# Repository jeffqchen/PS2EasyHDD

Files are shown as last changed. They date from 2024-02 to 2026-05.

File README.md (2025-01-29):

# PS2 EasyHDD

Many PS2 players use HDL/OPL with a traditional hard drive or SSD. This requires the PS2 network adapter. In order to transfer games quickly and reliably, removing the drive and hooking it up to a computer is the definitive method.

However, the adapter has an annoying design - it contains the hard drive inside the PS2 and requires unscrewing the adapter from the PS2 in order to gain access to the drive. I have endured this annoyance for two decades, and decided it is time to end this. (Not to mention the color-mismatch when you use a special edition PS2...)


  

This is the EasyHDD shell for the PS2 network adapters. It simply reverses the way the hard drive is installed and allows you to easily pull it out.

You only need to disassemble the original network adapter, and transplant necessary parts to the new shell to finish the job. The unused parts will not be harmed and you can simply stow them away.

Since the hard drive bay inside the PS2 is constrained, currently only 2.5 inch SATA drives are in the plans to be supported.

There are currently 3 main variants of the network adapter:
- SCPH-10350. The thin model with only a LAN port.
- SCPH-10281. The thick model with both a modem and a LAN port.
- Gamestar. A piece of bootleg hardware that only offers hard drive connectivity and no networking is implemented.




The plan is to support all of the mentioned models.

Current progress:
- SCPH-10350: Finished
- SCPH-10281: Finished
- Game Star: Finished

Please visit the [Project Wiki](https://github.com/jeffqchen/PS2EasyHDD/wiki) page for detailed instructions.

-----

# Special Thanks

Twitter Folks for Photos:
- @radiatedguinea
- @MrBildo

-----

Shield: [][cc-by-sa]

This work is licensed under a
[Creative Commons Attribution-ShareAlike 4.0 International License][cc-by-sa].

[][cc-by-sa]

[cc-by-sa]: http://creativecommons.org/licenses/by-sa/4.0/
[cc-by-sa-image]: https://licensebuttons.net/l/by-sa/4.0/88x31.png
[cc-by-sa-shield]: https://img.shields.io/badge/License-CC%20BY--SA%204.0-lightgrey.svg

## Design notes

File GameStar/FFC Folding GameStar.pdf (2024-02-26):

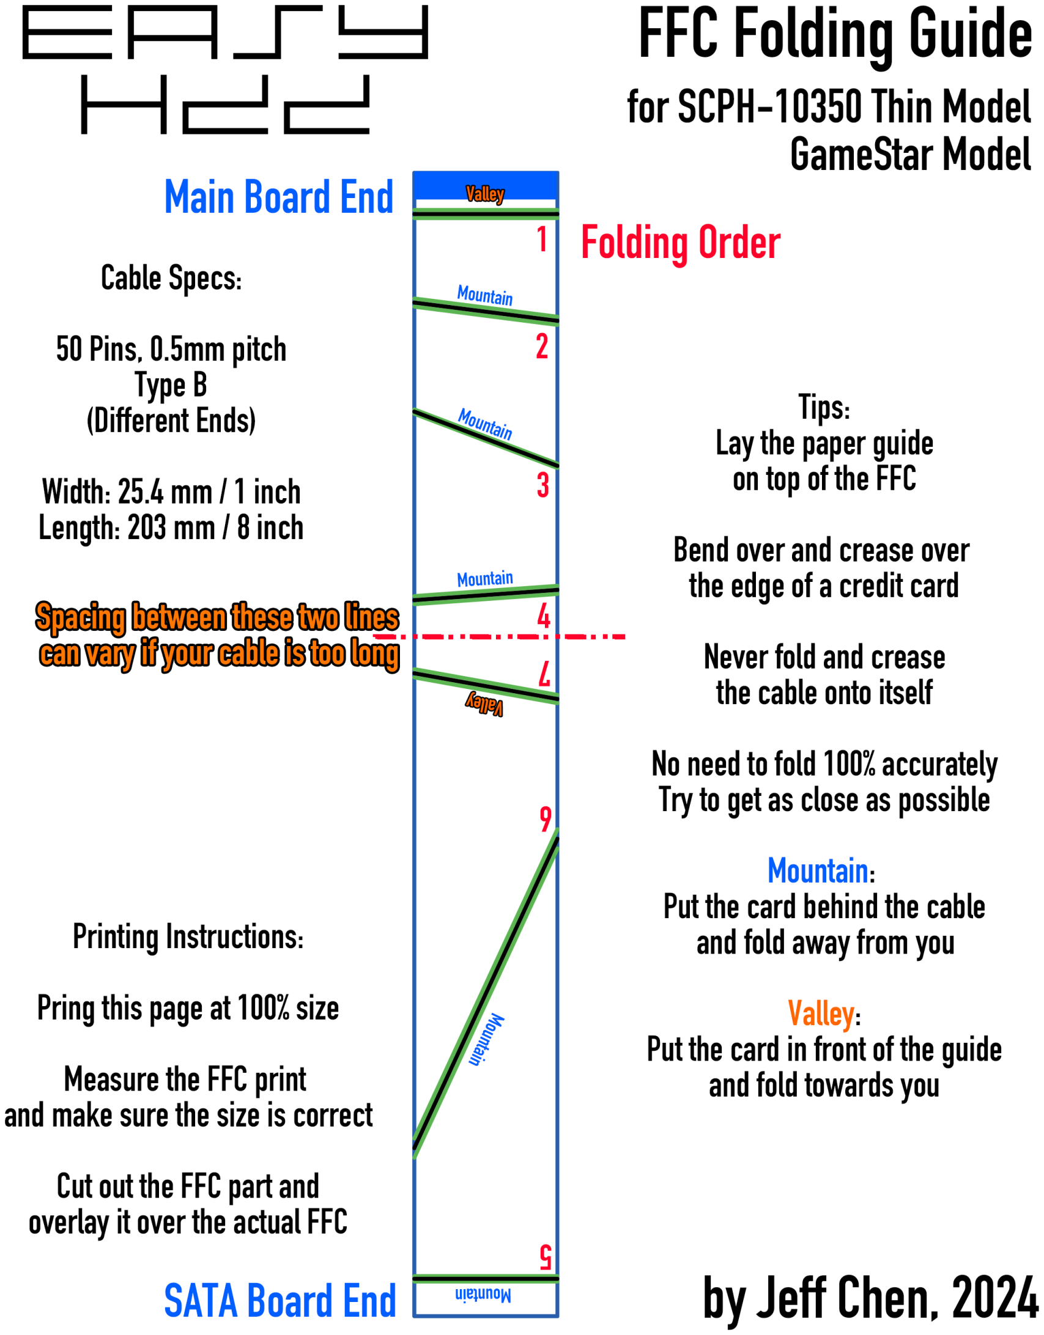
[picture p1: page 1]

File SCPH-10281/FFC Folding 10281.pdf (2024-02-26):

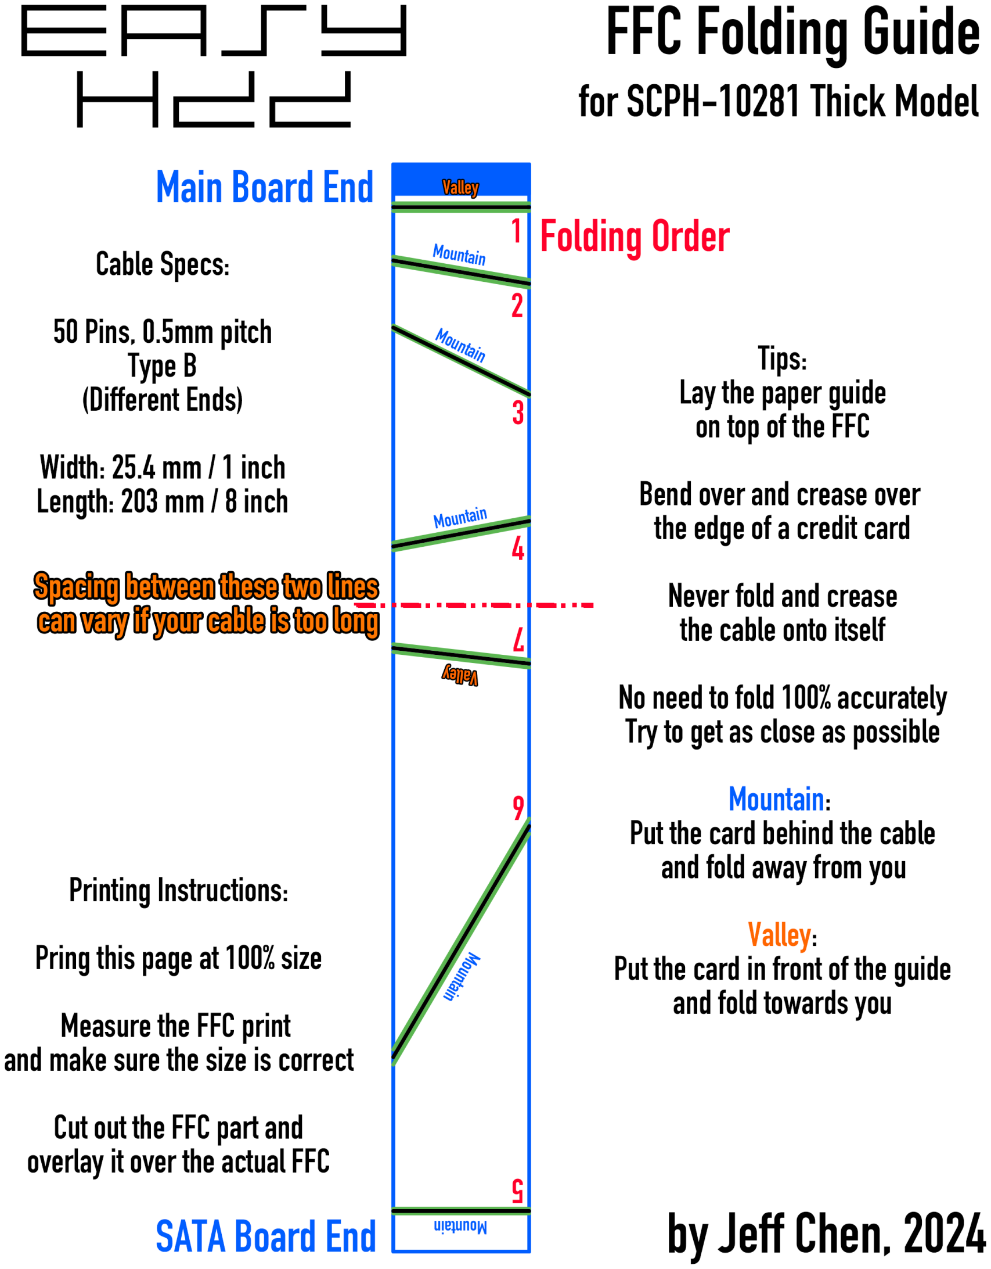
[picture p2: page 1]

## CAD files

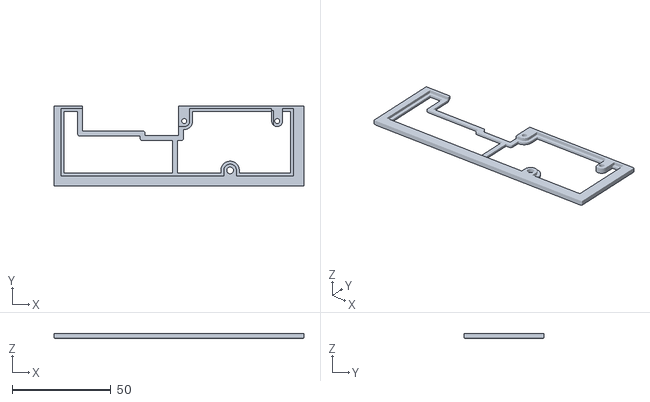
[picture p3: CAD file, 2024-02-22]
GameStar/3D Printing/Models Included In AIO/Main PCB Cover.stl
126.4 x 40.7 x 2.75

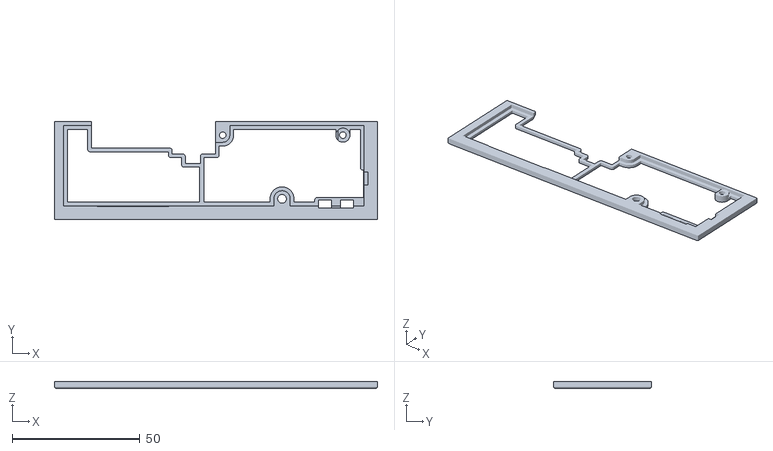
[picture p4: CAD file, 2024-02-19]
SCPH-10350/3D Printing/Models Included In AIO/Main PCB Cover.stl
126.4 x 38.2 x 2.75

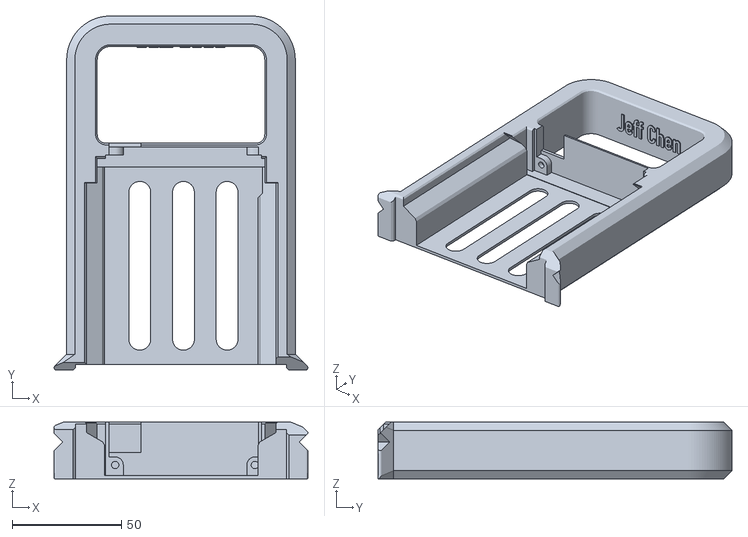
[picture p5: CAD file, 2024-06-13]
GameStar/3D Printing/Inner Tray Long.stl
116.3 x 162.2 x 26.0

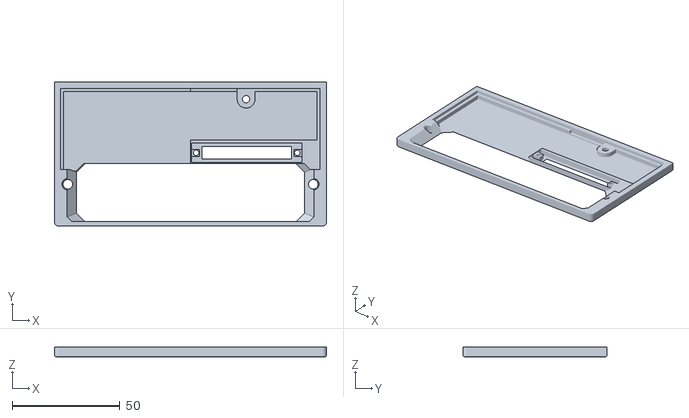
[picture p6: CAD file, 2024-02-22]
GameStar/3D Printing/Models Included In AIO/Inner Shell.stl
126.4 x 66.9 x 4.65

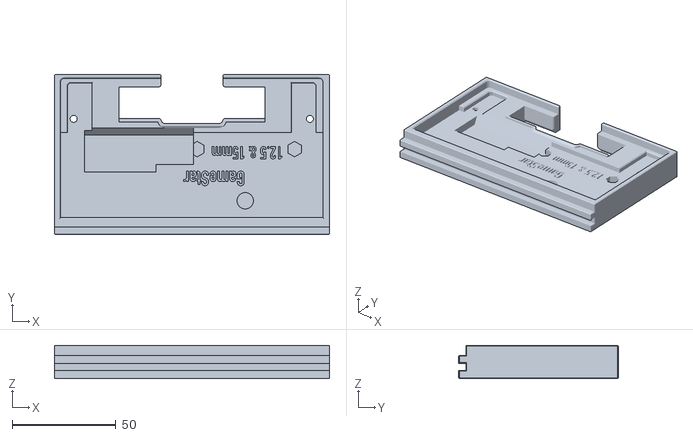
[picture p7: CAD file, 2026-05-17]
GameStar/3D Printing/Outer Shell & Tray Cover/Thick/Outer Shell 15mm.stl
132.8 x 77.0 x 16.1

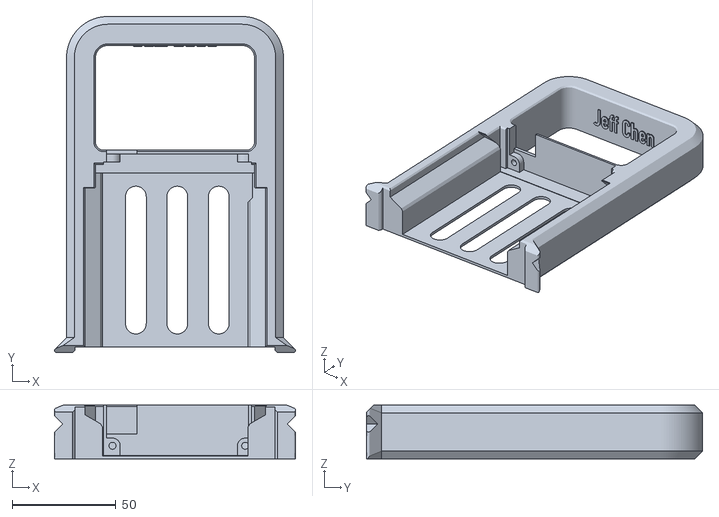
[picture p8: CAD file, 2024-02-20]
SCPH-10281/3D Printing/Inner Tray Long.stl
116.3 x 162.2 x 26.0

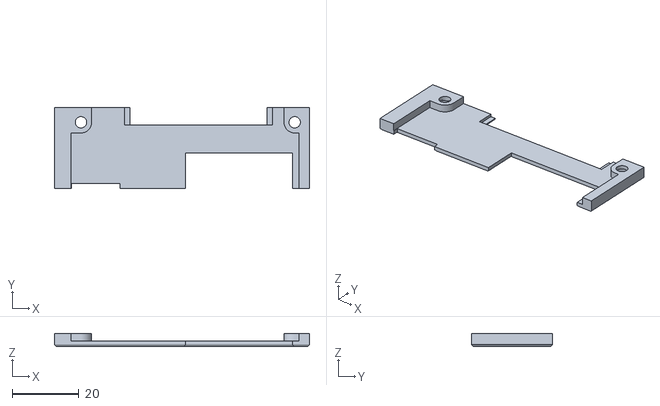
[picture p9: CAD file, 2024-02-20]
SCPH-10281/3D Printing/Models Included In AIO/Sata Board Cover.stl
76.3 x 24.4 x 3.82

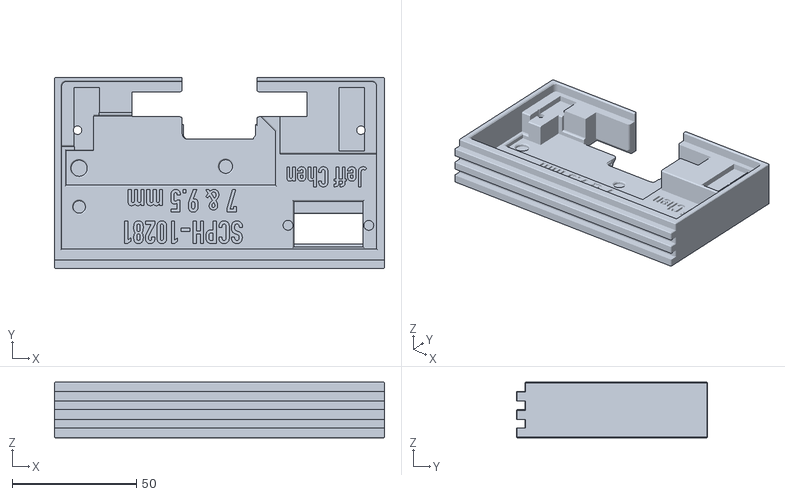
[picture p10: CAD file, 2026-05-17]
SCPH-10281/3D Printing/Outer Shell & Tray Cover/Outer Shell.stl
132.8 x 77.0 x 22.4

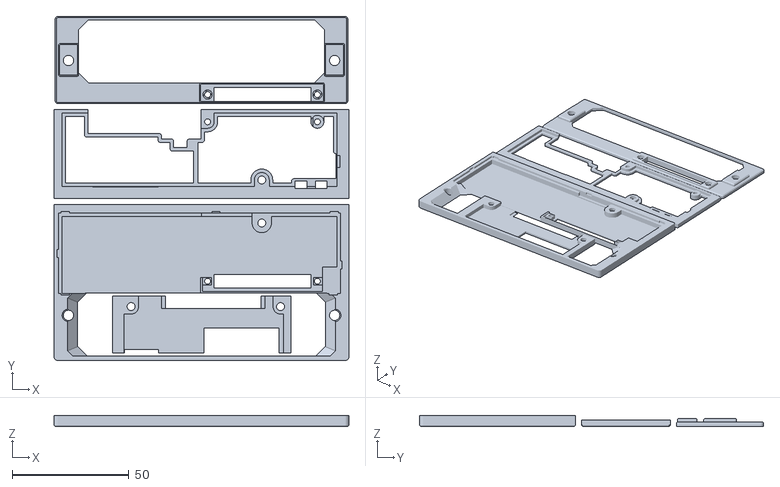
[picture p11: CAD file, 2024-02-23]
SCPH-10350/3D Printing/AIO for SCPH-10350.stl
126.4 x 147.4 x 4.65

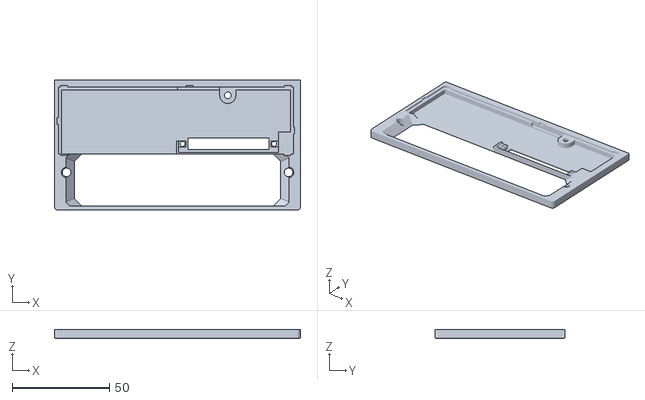
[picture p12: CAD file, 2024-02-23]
SCPH-10350/3D Printing/Models Included In AIO/Inner Shell.stl
126.4 x 66.9 x 4.65

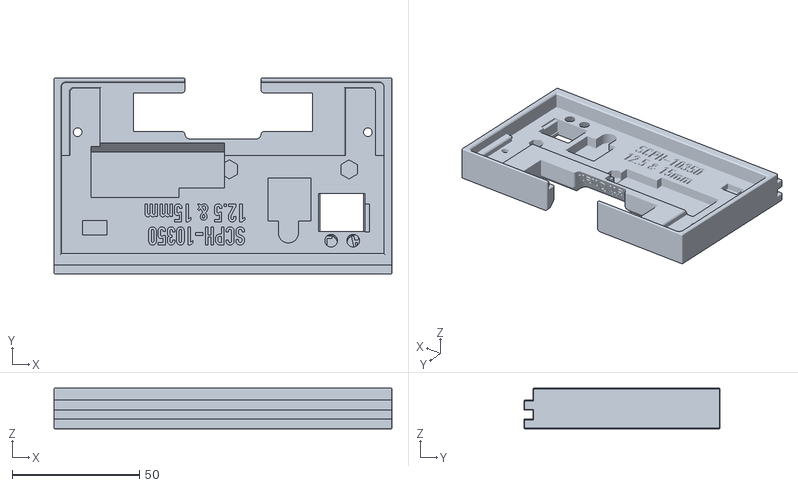
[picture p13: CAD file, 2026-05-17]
SCPH-10350/3D Printing/Outer Shell & Tray Cover/Thick/Outer Shell 15mm SPECIAL.stl
132.8 x 77.0 x 16.1

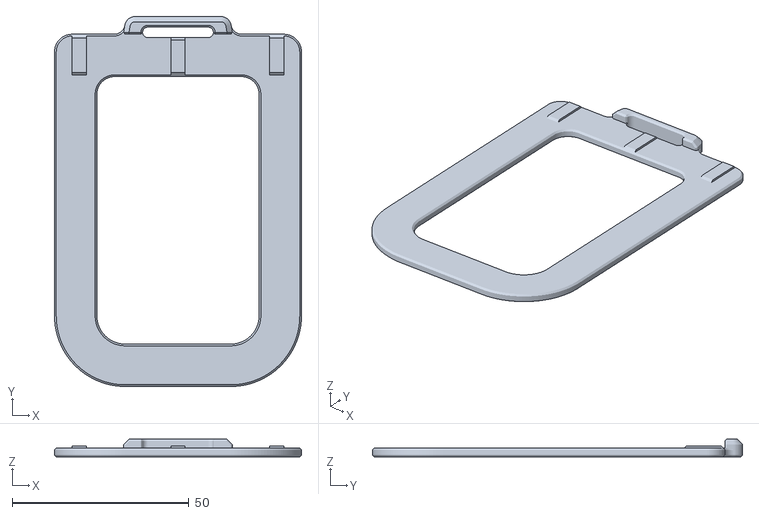
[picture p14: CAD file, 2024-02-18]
Tray Height Adapter.stl
69.9 x 104.6 x 5.00

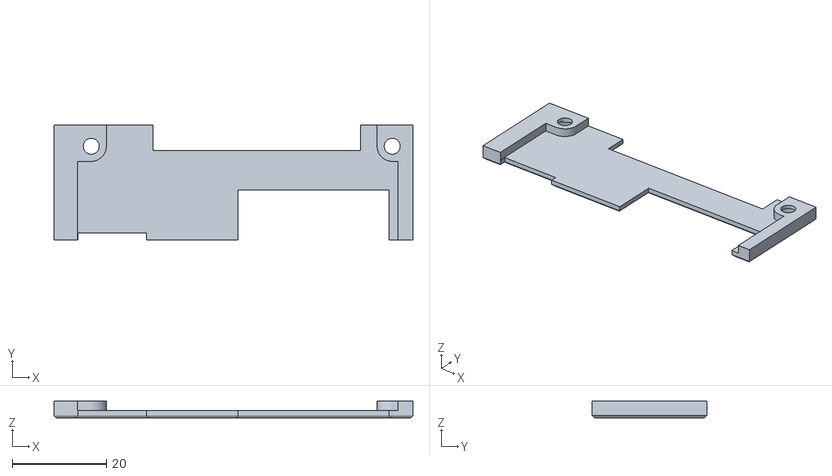
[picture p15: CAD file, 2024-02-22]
GameStar/3D Printing/Models Included In AIO/Sata Board Cover.stl
76.3 x 24.4 x 3.57

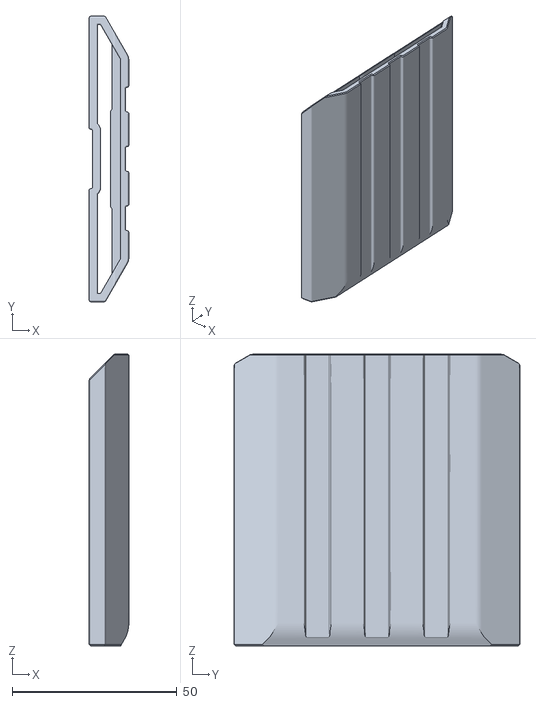
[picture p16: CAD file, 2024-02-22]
GameStar/3D Printing/Outer Shell & Tray Cover/Thick/Inner Tray Cover 12.5mm.stl
12.0 x 86.6 x 88.6

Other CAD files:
GameStar/3D Printing/Outer Shell & Tray Cover/Thin/Outer Shell 9.5mm.stl
SCPH-10350/3D Printing/Outer Shell & Tray Cover/Thin/Outer Shell 9.5mm.stl
GameStar/3D Printing/AIO for GameStar.stl
GameStar/3D Printing/Outer Shell & Tray Cover/Thin/Inner Tray Cover 9.5mm.stl
GameStar/3D Printing/Inner Tray Short.stl
GameStar/3D Printing/Models Included In AIO/Inner Spacer.stl
GameStar/3D Printing/Outer Shell & Tray Cover/Thick/Inner Tray Cover 15mm.stl
GameStar/3D Printing/Outer Shell & Tray Cover/Thin/Inner Tray Cover 7mm.stl
SCPH-10281/3D Printing/AIO for SCPH-10281.stl
SCPH-10281/3D Printing/Inner Tray Short.stl
SCPH-10281/3D Printing/Models Included In AIO/Inner Shell.stl
SCPH-10281/3D Printing/Models Included In AIO/Inner Spacer.stl
SCPH-10281/3D Printing/Models Included In AIO/Mid Frame.stl
SCPH-10281/3D Printing/Modem Board Cover.stl
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

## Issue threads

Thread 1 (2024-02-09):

Support for V1.0 purple SATA interface board

burgsth, 2024-02-09:
I have a V1.0 purple SATA interface board with a slightly different component layout.
It won't fit into the printed part.

If needed I can add more dimension informations.
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

jeffqchen, 2024-02-10:
I don't have the v1.0 board on hand, but I have found pictures online. This will not be accurate and could lead to issues. And it will take a bit of time to add to the models.

If you can't wait, consider getting a v2.0 for now.

jeffqchen, 2024-02-10:
I have added amends to the model to account for the extra components on the v1.0 board. Please check the updated files.

burgsth, 2024-02-10:
The FFC connector seems to be slightly larger than on v2.0 boards, they do not fit into the gap. Lack of about 0.5mm on each side.
Will dremel the FCC gap tomorrow, now I'm printing the inner tray and will test tomorrow.

jeffqchen, 2024-02-10:
Please download the latest Sata Board Cover.stl. I widened it by 1mm on each side.

burgsth, 2024-02-11:
The SATA board cover seems to be fine now. The component skip on the inner tray needs to be moved about 2mm to the right (away from power connector skip) to fit the component.

jeffqchen, 2024-02-11:
Fixed the Inner Tray. Please check again.

burgsth, 2024-02-12:
Everything fits perfect, thank you very much.
Now I'll print the mainboard parts.

jeffqchen, 2024-02-12:
Thank you very much for your help!

Closed 2024-02-12.

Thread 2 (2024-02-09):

Missing hole on other revision of Mainboard

burgsth, 2024-02-09:
I have a SCPH-10350 with a BA-005 Mainboard which lacks of the mounting hole of your uses BA-006.
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

The PCB seems to fit nearly into the case, so only a other position of the hole would be needed.
Only right side is slightly different.

jeffqchen, 2024-02-10:
I'll add that in soon. With the two existing holes, it should be sturdy enough to use for the time being.

jeffqchen, 2024-02-10:
I have moved the M3 screw position to use the hole you indicated. Please check the new files.

burgsth, 2024-02-13:
The right hole needs to be slightly larger
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

jeffqchen, 2024-02-13:
The two holes are of the same size. However since it's on a precarious location, it might end up being printed crooked. You can widen it by shoving the M3 hex screw driver bit into it and twist a few times.

burgsth, 2024-02-13:
Sorry, I ment the VS32AH hole. I've marked the part red.

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

On the other part, there are some condensators which need a change in the cover to fit. (marked black)

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

jeffqchen, 2024-02-13:
Did fixes according to your info. Please check the updated pieces.

jeffqchen, 2024-02-14:
Thanks. I've removed that stub. It only exists on the newer rev.

burgsth, 2024-02-14:
Assembles fine now without flaws, thank you very very much for your help!
Only thing maybe is to make the holes for screw heads slightly larger, I need to get screws with smaller heads.

I have some more slim and fat adapters. If you are interessted I can take a look at the mainboard revision and testprint your designs to verify.

jeffqchen, 2024-02-15:
Thank you for your help. I'm still working on the 10281 for now and it will be available as soon as it's verified by me personally. Hopefully all the fixes you suggested were already put in it. Thank you for all your help!

Closed 2024-02-15.

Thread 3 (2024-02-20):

10281 Inner Tray Short

aznrob, 2024-02-20:
Did you upload the incorrect 10281 Inner Tray Short? The one I printed are missing the indents shown in the tutorial.

jeffqchen, 2024-02-20:
If it looks more spacious, it's because I've been improving the design to be more compatible with different versions.

jeffqchen, 2024-02-20:
Sorry about the error. I used a wrong reference and it flattented the opening. Now it's fixed and updated.

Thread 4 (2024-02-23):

Fixes for GameStar Wiki page

hadess, 2024-02-23:
Not sure how to do PRs for the Wiki, so here goes:
```diff
- GameStar Disassmebly
+ GameStar Disassembly
```

```diff
- JST PH header housing
+ [2x] JST PH header housing
```

jeffqchen, 2024-02-23:
Thank you. I’ve fixed them.

Closed 2024-02-23.

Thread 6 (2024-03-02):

Incorrect number of cables

hadess, 2024-03-02:
Very important ;)

We just need 4 of the 5 cables in the JST plug if we make it ourselves, so:
```diff
+ [5x] Pre-crimped JST cable. 15cm long.
- [4x] Pre-crimped JST cable. 15cm long.
```

I've verified that this applies to the Gamestar variant, not sure about the others.

jeffqchen, 2024-03-02:
It's not incorrect. We are not gonna cheap out on a ground connection that GameStar decided to do just to save a few cents. We are not gonna sink down to their level.

hadess, 2024-03-02:
> It's not incorrect. We are not gonna cheap out on a ground connection that GameStar decided to do just to save a few cents. We are not gonna sink down to their level.

OK, I looked at the 3 install pages, and all three showed a 5-pin cable with 4 actual wires, hence why I filed this issue in the first place. I guess I'll install that last wire then ;)

Closed 2024-03-02.

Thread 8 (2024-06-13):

Gamestar - Inner Shell - Issue in model on port

stefanpausch, 2024-06-13:
The parts near the port connector print disconnected in the Inner Shell on the Gamestar model.

I printed this part a few weeks ago (with an older file) and there was no issue.

I tested different slicers and printers

Problem appears on 0.2 and higher. Print looks fine on 0.15 and lower

Example in prusaslicer :

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

jeffqchen, 2024-06-13:
This part is non-essential. It doesn't matter if it came out nasty, as long as the opening is not blocked.

Closed 2024-10-27.

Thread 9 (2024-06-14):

Cable length issue with SATA adapter v1.0 (info + fix)

juanmcasillas, 2024-06-14:
Hello,

First of all, thanks for your work, it's awesome. I found a weird problem while mounting the kit using the v 1.0 SATA adapter. It works with the short data wire (the wire used on the adapter) but when connected to the long data wire, some weird issues happens (sometimes PS2 won't detect the disk, other times the disk is read, games are listed but games doesn't load, and so on. I test with the SATA adapter v 2.0, and problems gone. It works flawesly with the long data wire without problems. So, if you plan to mount the kit, ensure you use the SATA adapter v 2.0 (the puple thing, you know).

Thanks again,

jeffqchen, 2024-06-14:
If you take a close look, early revisions have very bad layout with parallel traces in different lengths and turn 90º angles. I bet that's why they work badly with longer cables. I've mentioned that in the guides as well, I think.

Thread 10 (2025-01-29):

Alternate SATA board designs?

joonboi, 2025-01-29:
So I know it is specifically made for the purple v2.0 adapter, but I have a green v 2.1 adapter and there’s a component that is not allowing use, any chance at getting a Sata board alternative for other revisions of the sata board?

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

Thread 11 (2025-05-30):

file organization

orabeidm, 2025-05-30:
What kind of idiotic file organization is this? What kind of cataloging is that? I downloaded the archive for GameStar and now I see it's missing 3D models. I'm looking at the assembly instructions and it's immediately clear that the very first part needed isn't in the 3D model folders. Where am I supposed to look for them? Why not put everything in one place? Why not label them 1-2-3 and so on? I'm a professional design engineer with vast experience, and you can't imagine how angry I am trying to find anything in this repository!

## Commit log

2024-02-06 Upload 10350 files
    [AIO for SCPH-10350.stl, Inner Shell.stl, Inner Spacer.stl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]
2024-02-07 Create Tray Height Adapter.stl
    [Tray Height Adapter.stl]
2024-02-07 Update Tray Height Adapter.stl
    [Tray Height Adapter.stl]
2024-02-10 Design update 10350
    - Move main board M3 screw position
    - Add SATA board v1.0 compatibility.
    [AIO for SCPH-10350.stl, Inner Shell.stl, Inner Spacer.stl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]
2024-02-10 Add LED Lettering to 10350
    [Outer Shell 15mm SPECIAL.stl, Outer Shell 9.5mm SPECIAL.stl]
2024-02-10 Update Sata Board Cover.stl
    Widen FFC connector gap
    [Sata Board Cover.stl]
2024-02-11 Update AIO for SCPH-10350.stl
    [AIO for SCPH-10350.stl]
2024-02-11 Fix Inner Spacer Overhang
    [AIO for SCPH-10350.stl, Inner Spacer.stl]
2024-02-11 Update Inner Tray.stl
    [Inner Tray.stl]
2024-02-13 More older main board rev fixes
    [AIO for SCPH-10350.stl, Inner Shell.stl, Main PCB Cover.stl]
2024-02-14 Fix earlier mainboard
    [AIO for SCPH-10350.stl, Inner Shell.stl]
2024-02-16 Create Inner Tray Short.stl
    [Inner Tray Short.stl]
2024-02-18 Upload 10281 design files
    [AIO for SCPH-10281.stl, Inner Shell.stl, Inner Spacer.stl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]
2024-02-18 Update 10281 stl files
    [Inner Tray Long.stl, Mid Frame.stl, Modem Board Cover.stl]
2024-02-19 Upgrade to support all board revs
    (Hopefully)
    [AIO for SCPH-10281.stl, Inner Shell.stl, Inner Tray Long.stl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]
2024-02-19 Update Board Compatibility
    [AIO for SCPH-10281.stl, AIO for SCPH-10350.stl, Inner Shell.stl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]
2024-02-20 Fix plug issue for short tray
    [Inner Tray Short.stl]
2024-02-20 Make SATA cover slide in easier
    [Sata Board Cover.stl]
2024-02-20 Update details in trays
    [Inner Tray Long.stl, Inner Tray Short.stl]
2024-02-22 Upload GameStar Models
    [AIO for GameStar.stl, Inner Shell.stl, Inner Spacer.stl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]
2024-02-22 Update details of GameStar faceplate
    [Outer Shell 15mm.stl, Outer Shell 9.5mm.stl]
2024-02-22 Move Files
    [AIO for GameStar.stl, Inner Shell.stl, Inner Spacer.stl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]
2024-02-23 Fix ZM-027 board compatibility
    [AIO for SCPH-10350.stl, Inner Shell.stl, Outer Shell 15mm SPECIAL.stl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]
2024-06-13 Update Inner Tray Long.stl
    Fix the slope
    [Inner Tray Long.stl]
2025-05-31 Adjust file organization
    [Inner Shell.stl, Inner Spacer.stl, Inner Tray Cover 12.5mm.stl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]
2025-05-31 Move Tray Height Adapter
    [Tray Height Adapter.stl]
2026-05-17 Outer shell adjustments
    Reduce width back to match stock adapter shell
    [Outer Shell 15mm SPECIAL.stl, Outer Shell 15mm.stl, Outer Shell 9.5mm SPECIAL.stl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]

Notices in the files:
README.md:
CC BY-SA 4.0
